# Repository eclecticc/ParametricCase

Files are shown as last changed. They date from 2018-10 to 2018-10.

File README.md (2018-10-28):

# Parametric Case
An open source 3D printable PC case that can fit your components exactly by adjusting a few parameters.

by Nirav Patel http://eclecti.cc

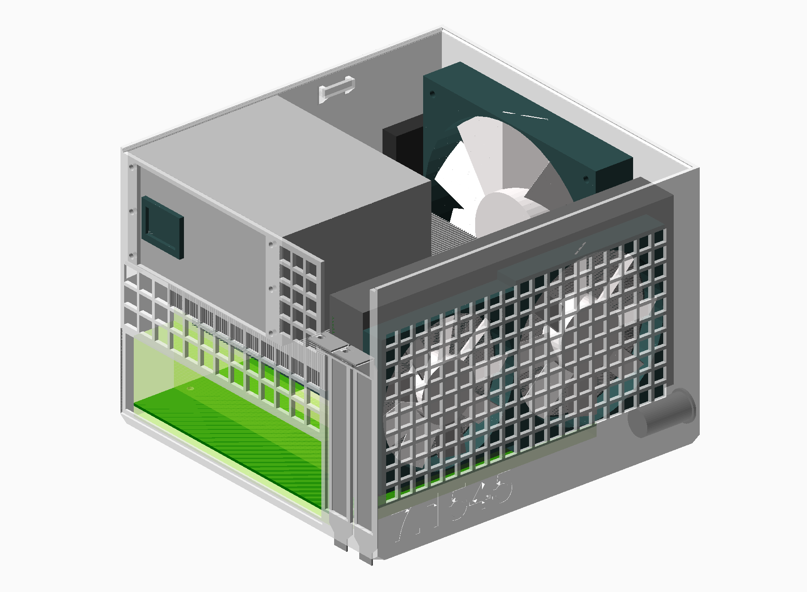
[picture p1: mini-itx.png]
Example Case


# License
See [LICENSE](/LICENSE)

# Instructions
The case is fully built out in OpenSCAD, an open source parametric modeling tool http://www.openscad.org/

You can generate printable stl files from that quickly by adjusting a few parameters to match your components.

If you happen to own the same components as I do (Noctua NH-L12s, Zotac 1080 Mini, SFX PSU), you can also just
use the example stl files directly.

## Parameters to edit
In mini-itx.scad, you'll need to choose the power supply type (psu_type of "sfx", "sfx-l", or "flexatx), the CPU heatsink
(heatsink_type of "aio", "noctua_nh_l12s", "noctua_nh_u9s", "cryorig_c7", or create your own), and probably measure
your GPU if you don't happen to own the Zotac 1080 Mini like I do.

    traditional(show_body = true, show_lid = false, show_internals = false, heatsink_type = "noctua_nh_l12s", psu_type = "sfx");

Beyond that, there are a range of optional items you can adjust.
 * The front fan with case_fan_size and case_fan_thickness
 * Ventilation for the m2 slot on your motherboard with m2_location
 * Extra clearance for your gpu power plug if needed with gpu_power_height
 * Airflow clearance for your heatsink if you want more than the default 5mm with cpu_fan_clearance
 * Thickness of all walls with wall in defaults.scad
 
## Printing
You'll need to print the body and the lid one at a time.  Note that the case is likely going to push up to or past
the size limits of many consumer 3d printers.  I've been printing them pretty successfully on a Prusa i3 MK3.

The case should print without any support required except for on the back panel around the motherboard i/o and power supply.
Cura allows you to block out support generation in other areas, and I assume other slicers do as well.

The default wall thickness with 20% infill should be more than stong enough, but you can adjust it up or down if needed.

I've found each case to require around 350-400g of filament, so be prepared for that.  You'll also want to make sure your
printer is outputting dimensionally correct prints, otherwise you're going to have a challenging time with assembly.

If you want the anti-vibration feet to actually anti-vibrate, you should print those with TPU or similar.

## Assembly
I use 5mm diameter M3 brass threaded inserts rather than screwing directly into the plastic for the motherboard and GPU.
Using a soldering iron with a blunt tip, you can heat press the insert into the plastic pretty easily.  Beyond that, you'll
want M3 screws, fan screws for your fan, and also #6-32 screws for your power supply.

Since the case is bucket shaped, you'll want to plug as many cables as you can into your motherboard outside
of the case and then drop the fully loaded motherboard down into the case.  After screwing the motherboard into the
threaded inserts, you can install the power supply and the GPU.

## Advanced editing
I only have the traditional "shoebox" style architecture built out, but all of the building blocks are in place to easily
build non-traditional case layouts.  You'll want to double check a lot of the dimensions though, especially around the GPU.

# Known Issues
Pull requests are welcome on any of these.
 * The PCI bracket/gpu height is probably wrong, but I haven't dug into the math enough to figure out where.
 * The top cover doesn't stay on well.  Realistically it should be screwed into place rather than slid in.
 * Overall rigidity of the case is not awesome with 2.5mm walls in PLA.  Extra structure would probably improve it.

## Feature Opportunities
 * Currently only a traditional shoebox layout is present.  Alternate layouts would be great.
 * There are a limited number of heatsink options currently.
 * Alternative vent shapes would be helpful.

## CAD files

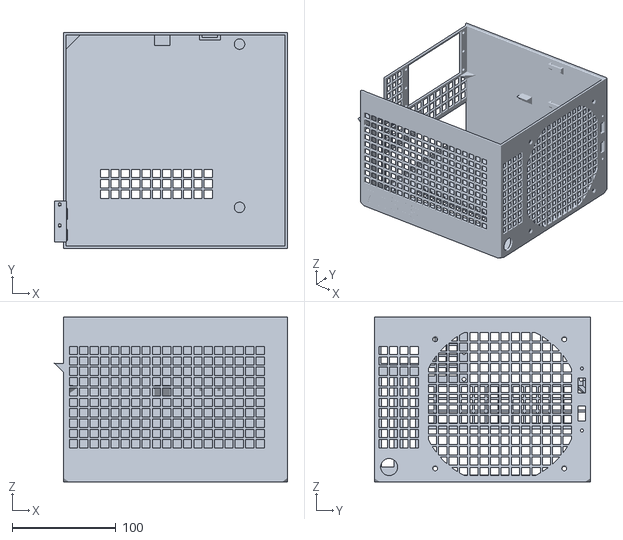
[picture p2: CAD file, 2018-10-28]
mini-itx.stl
224.8 x 208.6 x 158.8

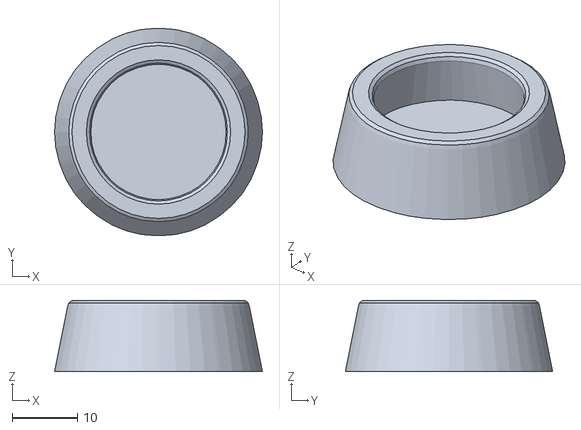
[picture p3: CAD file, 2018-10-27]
feet.stl
32.0 x 31.9 x 11.0

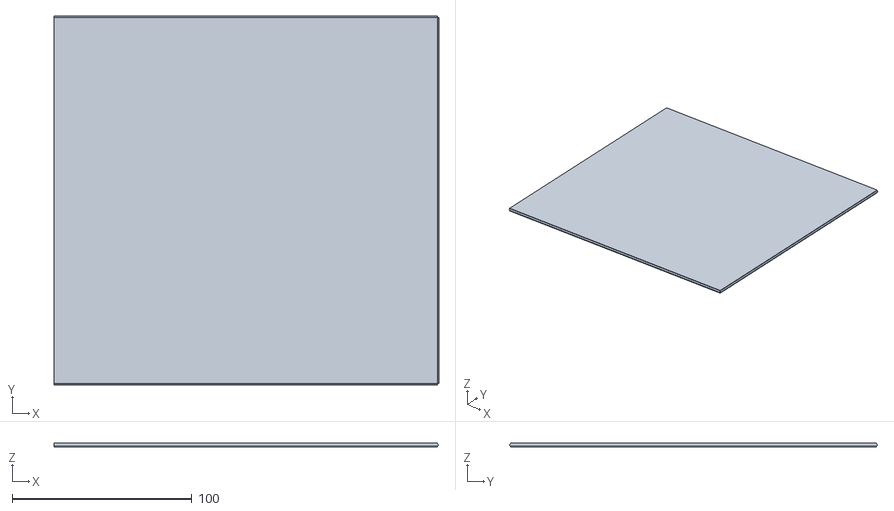
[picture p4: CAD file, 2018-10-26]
mini-itx-lid.stl
214.4 x 205.4 x 2.50

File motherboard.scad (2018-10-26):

// Parametric Mini-ITX Case
// https://github.com/eclecticc/ParametricCase
//
// BSD 2-Clause License
// Copyright (c) 2018, Nirav Patel, http://eclecti.cc
//
// Motherboard modules

include <defaults.scad>;

// Base PCB dimensions
miniitx = [170, 170, pcb_thickness];

// Motherboard mounting hold diameter and offsets (relative to hole c)
miniitx_hole = 3.96;
miniitx_hole_c = [10.16, 6.35];
miniitx_hole_f = [22.86, 157.48];
miniitx_hole_h = [154.94, 0];
miniitx_hole_j = [154.94, 157.48];

// Keepouts on top and bottom of board
miniitx_bottom_keepout = 0.25 * 25.4;

// AM4 Socket specs
am4_holes = [80, 95, 54, 90]; // Center not measured
am4_socket = [40, 40, 7.35]; // Not measured

// Offset from origin corner of motherboard to the base of the PCI-e card
pci_e_offset = [46.94+10.16, 47.29-45.72+6.35, 114.55-111.15];

module motherboard_miniitx(show_keepouts, socket_holes, socket) {
    area_a_keepout = [27, 15, 170-27-30, 170-15, 57];
    area_b_keepout = [0, 0, 170, 15, 16];
    area_c_keepout = [170-30, 15, 30, 170-15, 38];
    area_d_keepout = [0, 15, 27, 170-15, 39];
    $fn = 20;
    
    difference() {
        union() {
            // The PCB
            color("Green", 1.0) {
                cube(miniitx);
            }
            translate([socket_holes[0]-socket[0]/2, socket_holes[1]-socket[1]/2, miniitx[2]]) {
                color("OldLace", 1.0) {
                    cube(socket);
                }
            }
        }
        
        // Mounting holes for the motherboard
        translate([miniitx_hole_c[0], miniitx_hole_c[1], -extra/2]) {
            cylinder(r = miniitx_hole/2, h = miniitx[2]+extra);
            for (hole = [miniitx_hole_f, miniitx_hole_h, miniitx_hole_j]) {
                translate([hole[0], hole[1], 0]) cylinder(r = miniitx_hole/2, h = miniitx[2]+extra);
            }
        }
        
        // Mounting holes for the CPU cooler
        translate([socket_holes[0], socket_holes[1], -extra/2]) {
            for (i = [-socket_holes[2]/2, socket_holes[2]/2]) {
                for (j = [-socket_holes[3]/2, socket_holes[3]/2]) {
                    translate([i, j, 0]) cylinder(r = miniitx_hole/2, h = miniitx[2]+extra);
                }
            }
        }
    }
    
    // PCI-e slot
    color("DarkSlateGray", 1.0) {
        translate([pci_e_offset[0]-14.5, pci_e_offset[1]-7.5/2, miniitx[2]]) cube([89.0, 7.5, 11.25]);
    }
    
    // Keepouts for visualization purposes
    color("GreenYellow", 0.25) {
        if (show_keepouts == true) {
            translate([0, 0, -miniitx_bottom_keepout]) cube([miniitx[0], miniitx[1], miniitx_bottom_keepout]);
            
            for (keepout = [area_a_keepout, area_b_keepout, area_c_keepout, area_d_keepout]) {
                translate([keepout[0], keepout[1], miniitx[2]]) {
                    cube([keepout[2], keepout[3], keepout[4]]);
                }
            }
        }
    }
}

motherboard_back_edge = miniitx_hole_c[0]-12.27;
motherboard_back_panel_overhang = 158.75+7.52+6.35-miniitx[1];
motherboard_back_panel_lip = 2.54;
motherboard_back_panel_size = [158.75, 44.45];

module motherboard_back_panel_cutout() {
    // Cut-out for the back panel i/o
    translate([-extra/2+motherboard_back_edge-wall, miniitx_hole_c[1]+7.52, -2.24]) {
        cube([extra/2+wall+motherboard_back_edge+39, motherboard_back_panel_size[0], motherboard_back_panel_size[1]]);
        // Thin a 2.54mm area around the i/o down to a typical sheet metal thickness
        translate([0, -motherboard_back_panel_lip, -motherboard_back_panel_lip]) cube([extra/2+wall-1.2, 158.75+motherboard_back_panel_lip*2, 44.45+motherboard_back_panel_lip*2]);
    }
}

//motherboard_miniitx(false, am4_holes, am4_socket);
//% motherboard_back_panel_cutout();

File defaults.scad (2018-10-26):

// Parametric Mini-ITX Case
// https://github.com/eclecticc/ParametricCase
//
// BSD 2-Clause License
// Copyright (c) 2018, Nirav Patel, http://eclecti.cc
//
// Convenience defaults that apply across all modules

// Some default convenience variables
extra = 1.0;
// Thickness of case walls
wall = 2.5;
// Default PCB thickness for motherboard and GPU
pcb_thickness = 1.57;

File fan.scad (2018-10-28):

// Parametric Mini-ITX Case
// https://github.com/eclecticc/ParametricCase
//
// BSD 2-Clause License
// Copyright (c) 2018, Nirav Patel, http://eclecti.cc
//
// Case fan modules

include <defaults.scad>;
include <vent.scad>;

_hole_spacings=[
        [220, 170],
        [200, 154],
        [140, 124.5],
        [120, 105],
        [92, 83],
        [80, 72],
        [70, 60],
        [60, 50],
        [50, 40],
        [40, 32]
        ];

function hole_spacing(size) = _hole_spacings[search([size], _hole_spacings, 1, 0)[0]][1];

fan_screw_r = 4.4;
fan_screw_head_r = 6.6;

module fan(size, thickness, blades) {
    // Center at base of exhaust side is datum
    $fn = 50;
    fan_wall = 1;
    hole_spacing = hole_spacing(size);
    
    color("DarkSlateGray", 1.0) {
        difference() {
            translate([-size/2, -size/2, 0]) {
                cube([size, size, thickness]);
            }
            translate([0, 0, -extra/2]) cylinder(r = size/2-fan_wall, h = thickness + extra);
            
            // Holes for the fan screws
            for (x = [-hole_spacing/2, hole_spacing/2]) {
                for (y = [-hole_spacing/2, hole_spacing/2]) {
                    translate([x, y, -extra/2]) cylinder(r = fan_screw_r/2, h = thickness+extra);
                }
            }
        }
    }
    
    color("Snow", 1.0) {
        cylinder(r = size/5, h = thickness);
        intersection() {
            for (i = [0:blades]) {
                rotate([0, 0, i*360/blades]) translate([0, -thickness/2, thickness/4]) rotate([-60, 0, 0]) cube([size/2, 1, thickness]);
            }
            cylinder(r = size/2-fan_wall*2, h = thickness);
        }
    }
}

module fan_cutout(size) {
    $fn = 20;
    hole_spacing = hole_spacing(size);
    
    vent_rounded_rect(size/2*1.1, [size, size], 10, 2.0);
    
    // Countersunk holes for the fan screws
    for (x = [-hole_spacing/2, hole_spacing/2]) {
        for (y = [-hole_spacing/2, hole_spacing/2]) {
            translate([x, y, 0]) {
                cylinder(r = fan_screw_head_r/2, h = 15);
                translate([0, 0, -1.2]) cylinder(r1 = fan_screw_r/2, r2 = fan_screw_head_r/2, h = 1.2);
                translate([0, 0, -15]) cylinder(r = fan_screw_r/2, h = 15);
            }
        }
    }
}

//fan(120, 25, 9);
//% fan_cutout(120);

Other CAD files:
feet.scad
front_panel.scad
gpu.scad
heatsink.scad
mini-itx.scad
pci_bracket.scad
power_switch.scad
psu.scad
vent.scad

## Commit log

2018-09-10 Initial creation
    [mini-itx.scad]
2018-09-11 Full gpu implementation
    [mini-itx.scad]
2018-09-14 motherboard standoffs
    [mini-itx.scad]
2018-09-16 all walls in place
    [mini-itx.scad]
2018-09-17 improved ventilation
    [mini-itx.scad]
2018-09-19 SFX PSU and AIO
    [mini-itx.scad]
2018-09-19 refactor into multiple files
    [defaults.scad, fan.scad, gpu.scad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]
2018-09-20 Handle heatsinks and power supplies programmatically
    [heatsink.scad, mini-itx.scad, psu.scad]
2018-09-20 properly parametric case sizing
    [heatsink.scad, mini-itx.scad, vent.scad]
2018-09-23 fix clearance, fan location, width
    [mini-itx.scad, psu.scad]
2018-09-26 m2 ssd ventilation
    [mini-itx.scad]
2018-09-26 separate top cover
    [mini-itx.scad, psu.scad]
2018-09-26 extra bit sticking out on the lid
    [mini-itx.scad]
2018-10-05 Fix fan hole dimensions
    [fan.scad]
2018-10-05 Use 6-32 screw holes for PSUs
    [psu.scad]
2018-10-05 Minor dimensional fixes on PSU, GPU
    [gpu.scad, mini-itx.scad]
2018-10-05 Add horizontal back panel vent when using SFX
    [mini-itx.scad]
2018-10-06 fix pci bracket threaded insert, gpu clearance, corner printability
    [defaults.scad, mini-itx.scad]
2018-10-07 add power switch
    [mini-itx.scad, power_switch.scad]
2018-10-26 give the zotac 1080 a little more breathing room
    [gpu.scad]
2018-10-26 add front panel usb
    [front_panel.scad]
2018-10-26 give the GPU bracket a little more space
    [pci_bracket.scad]
2018-10-26 Cleaning up the housing for release
    Added cable management
    Added front panel
    Minor edits all around
    [mini-itx.scad]
2018-10-26 make the body view the default one, add header
    [mini-itx.scad]
2018-10-26 add license headers
    [defaults.scad, fan.scad, front_panel.scad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]
2018-10-26 Example STL files
    [mini-itx-lid.stl, mini-itx.stl]
2018-10-27 add anti-vibration feet
    [feet.scad, feet.stl]
2018-10-27 feet printing
2018-10-28 adjust fan screw size
    [fan.scad]
2018-10-28 move power switch away from wall
    [mini-itx.scad]
2018-10-28 thin out around the io cutout
    [pci_bracket.scad]
2018-10-28 update stl with minor fixes
    [mini-itx.scad, mini-itx.stl]
2018-10-28 switch to white background for image
